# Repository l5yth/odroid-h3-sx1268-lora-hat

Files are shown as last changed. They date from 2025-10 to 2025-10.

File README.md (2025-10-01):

# odroid-h3-sx1268-lora-hat

Kicad files for an ODROID H3/H3+ to Raspberry-Pi pin header translator to be used with the Waveshare SX1268 LoRa hat.

* Discussion: [forum.odroid.com/topic/50464](https://forum.odroid.com/viewtopic.php?f=171&t=50464&p=400427)
* Waveshare SX1268 LoRa schematics: [files.waveshare.com/SX1268_LoRa_HAT_SchDoc.pdf](https://files.waveshare.com/upload/a/af/SX1268_LoRa_HAT_SchDoc.pdf)
* ODROID H3 schematics: [wiki.odroid.com/odroid-h3/odroid-h3_rev2.0_20220406.pdf](https://wiki.odroid.com/_media/odroid-h3/odroid-h3_rev2.0_20220406.pdf)

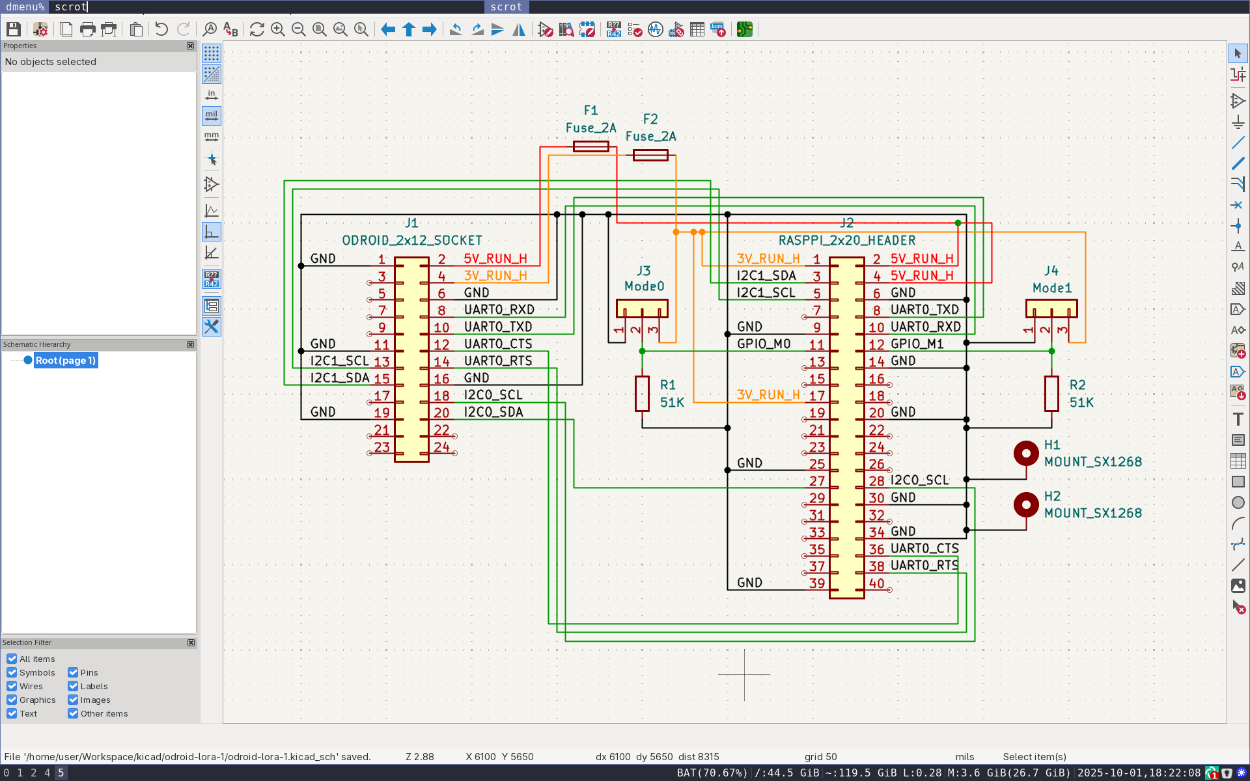
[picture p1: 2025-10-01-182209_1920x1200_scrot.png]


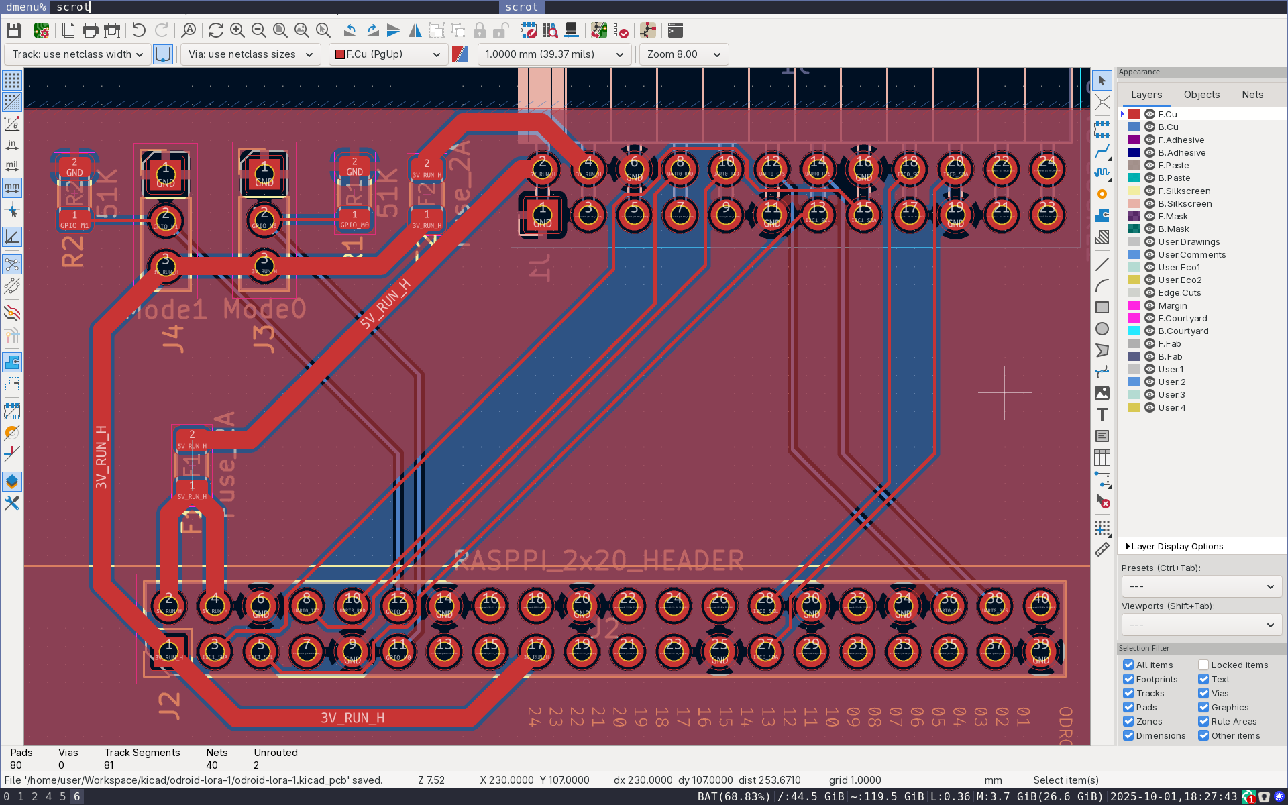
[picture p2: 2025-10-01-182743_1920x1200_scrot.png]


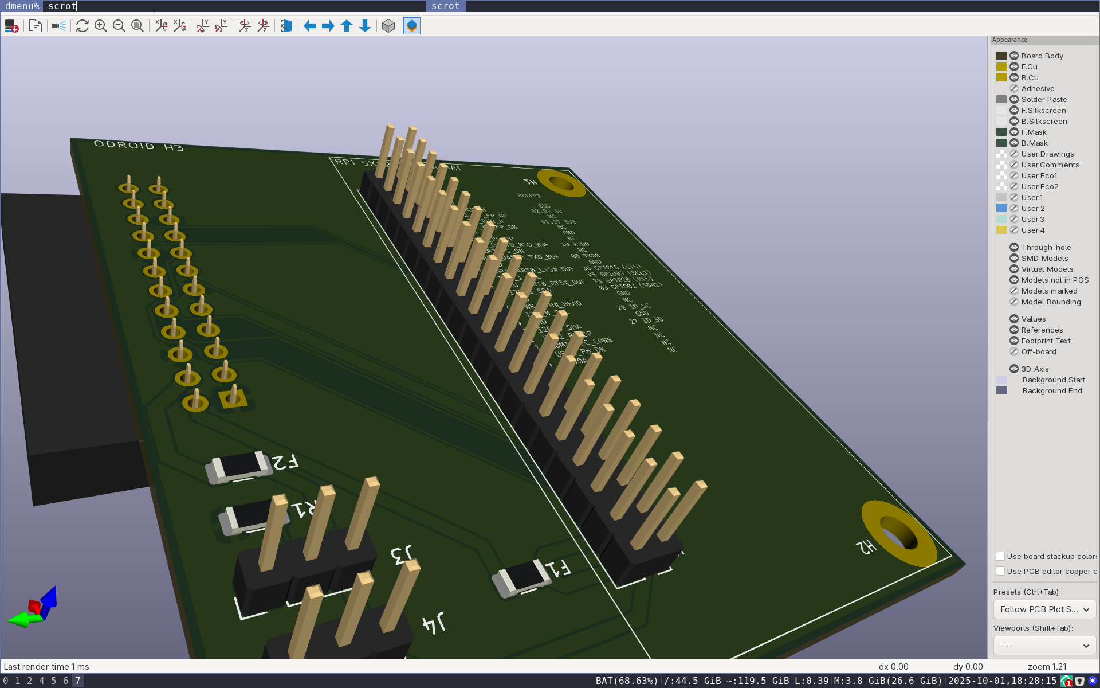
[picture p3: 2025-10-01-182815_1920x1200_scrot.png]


## LICENSE

CC0 - public domain

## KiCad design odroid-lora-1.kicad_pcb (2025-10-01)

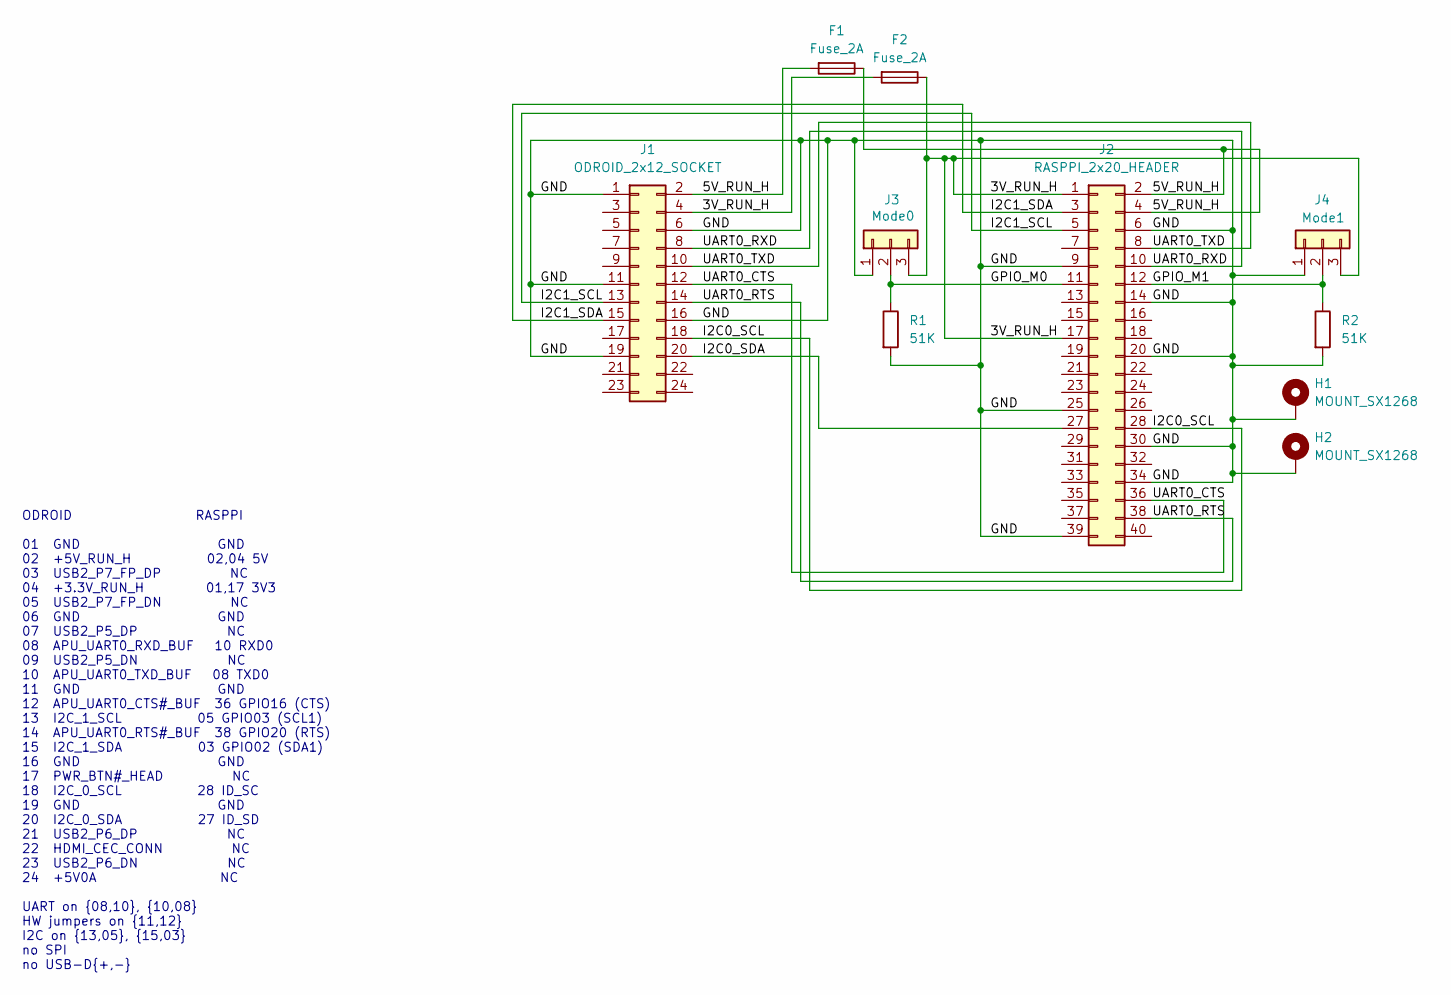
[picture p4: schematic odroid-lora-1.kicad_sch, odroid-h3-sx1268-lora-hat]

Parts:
F1, F2: Fuse_2A; Fuse_1206_3216Metric
H1, H2: MOUNT_SX1268; MountingHole_3.5mm_Pad
J1: ODROID_2x12_SOCKET; PinSocket_2x12_P2.54mm_Horizontal
J2: RASPPI_2x20_HEADER; PinHeader_2x20_P2.54mm_Vertical
J3: Mode0; PinHeader_1x03_P2.54mm_Vertical
J4: Mode1; PinHeader_1x03_P2.54mm_Vertical
R1, R2: 51K; R_1206_3216Metric

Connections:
/3V_RUN_H: F2.1, F2.2, J1.4, J2.1, J2.17, J3.3, J4.3
/5V_RUN_H: F1.1, F1.2, J1.2, J2.2, J2.4
/GND: H1.1, H2.1, J1.1, J1.6, J1.11, J1.16, J1.19, J2.6, J2.9, J2.14, J2.20, J2.25, J2.30, J2.34, J2.39, J3.1, J4.1, R1.2, R2.2
/GPIO_M0: J2.11, J3.2, R1.1
/GPIO_M1: J2.12, J4.2, R2.1
/I2C0_SCL: J1.18, J2.28
/I2C0_SDA: J1.20, J2.27
/I2C1_SCL: J1.13, J2.5
/I2C1_SDA: J1.15, J2.3
/UART0_CTS: J1.12, J2.36
/UART0_RTS: J1.14, J2.38
/UART0_RXD: J1.8, J2.10
/UART0_TXD: J1.10, J2.8

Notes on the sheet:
ODROID RASPPI 01 GND GND 02 +5V_RUN_H 02,04 5V 03 USB2_P7_FP_DP NC 04 +3.3V_RUN_H 01,17 3V3 05 USB2_P7_FP_DN NC 06 GND GND 07 USB2_P5_DP NC 08 APU_UART0_RXD_BUF 10 RXD0 09 USB2_P5_DN NC 10 APU_UART0_TXD_BUF 08 TXD0 11 GND GND 12 APU_UART0_CTS#_BUF 36 GPIO16 (CTS) 13 I2C_1_SCL 05 GPIO03 (SCL1) 14 AP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

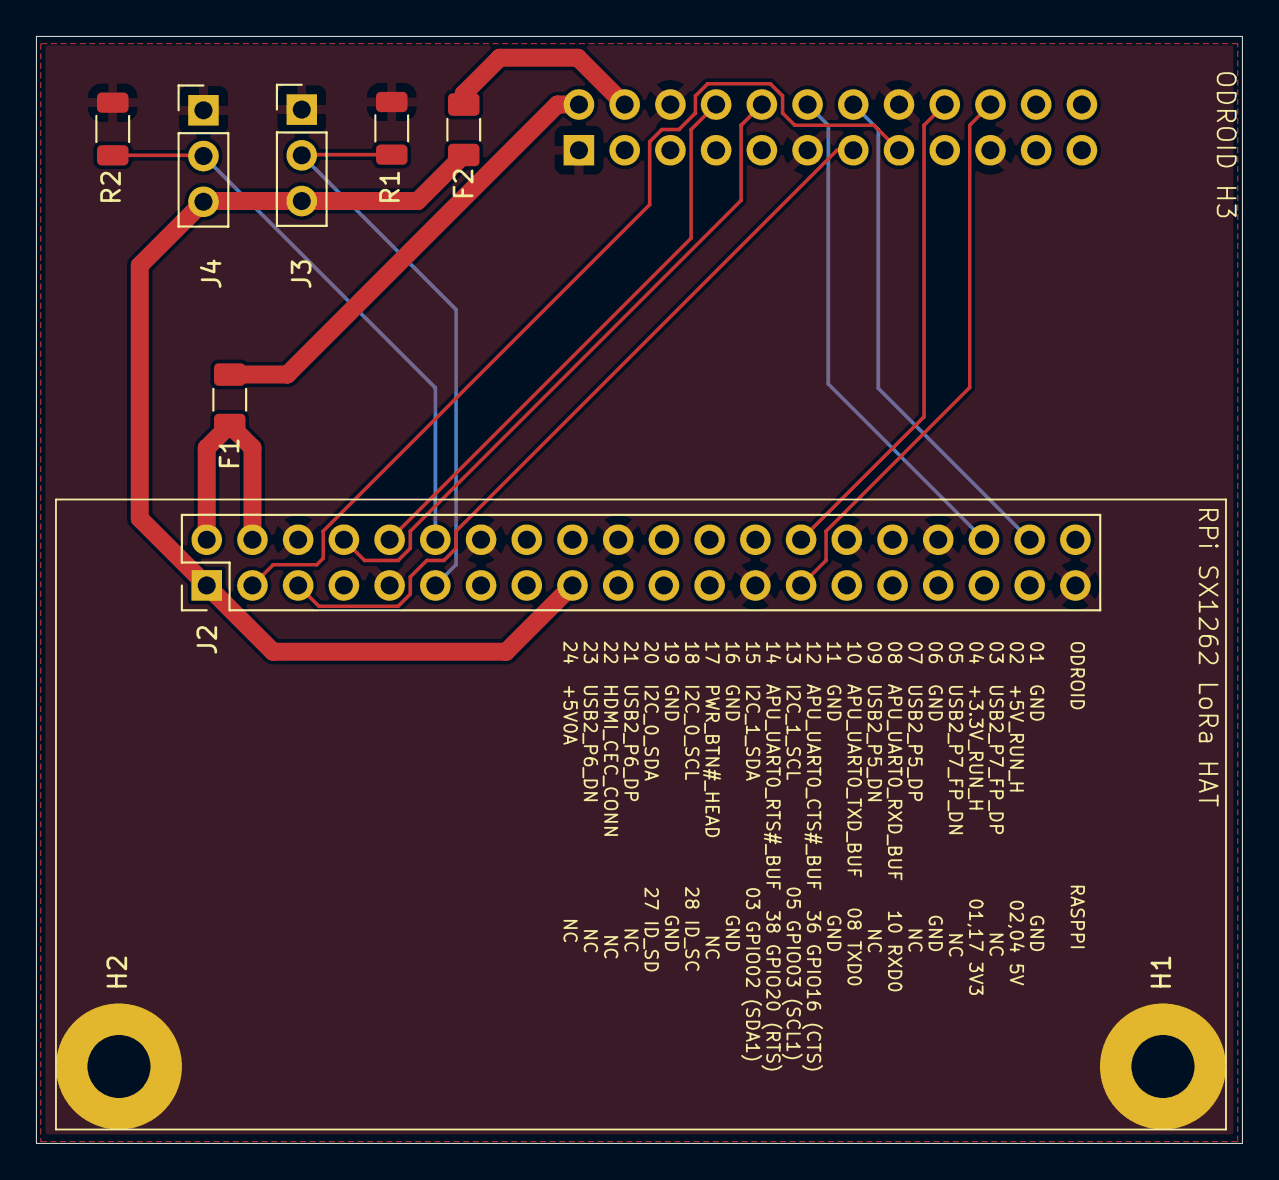
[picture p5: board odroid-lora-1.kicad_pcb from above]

Board: 2 copper layers, 67.0 x 61.5 mm, 10 parts (1 on the bottom side), 13 nets.

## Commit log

2025-09-27 add sx1268 lora hat for odroid kicad files
    [odroid-lora-0.kicad_pcb, odroid-lora-0.kicad_sch]
2025-09-27 rename project files
    [odroid-lora-1.kicad_pcb, odroid-lora-1.kicad_sch]
2025-09-27 update to angled condensed design
    [odroid-lora-1.kicad_pcb, odroid-lora-1.kicad_sch]
2025-09-28 replace pinheader with pinsocket for the odroid connector
    [odroid-lora-1.kicad_pcb, odroid-lora-1.kicad_sch]
2025-09-29 define power nets and increase trace width for currents
    [odroid-lora-1.kicad_pcb, odroid-lora-1.kicad_sch]
2025-10-01 add fuses
    [odroid-lora-1.kicad_pcb, odroid-lora-1.kicad_sch]
